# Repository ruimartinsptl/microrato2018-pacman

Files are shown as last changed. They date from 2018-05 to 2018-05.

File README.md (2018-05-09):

# PACMAN
## Micro Rato 2018
Neste repositório encontram o material necessário para criarem um robot micro-rato igual ao da nossa equipa. Disponibilizamos aqui:

* Modelos 3D
* Codigo para fazerem o vosso proprio farol emissor
* Esquema com as ligações de electronica
* Classes criadas por nós para aceder ao Hardware com alguns exemplos de utilização no código main
* Ferramenta de Debug em Python
* Relatório apresentado ao Juri

De forma a sermos mais eficientes, utilizamos o platformio para gerar os nossos makefiles, e utilizamos o CLion como IDE. Para comunicar com o robot usamos um ESP acoplado ao rato que tinha como função programar o rato remotamente via wifi. Entras aqui a respectiva documentação.

### O Robot:

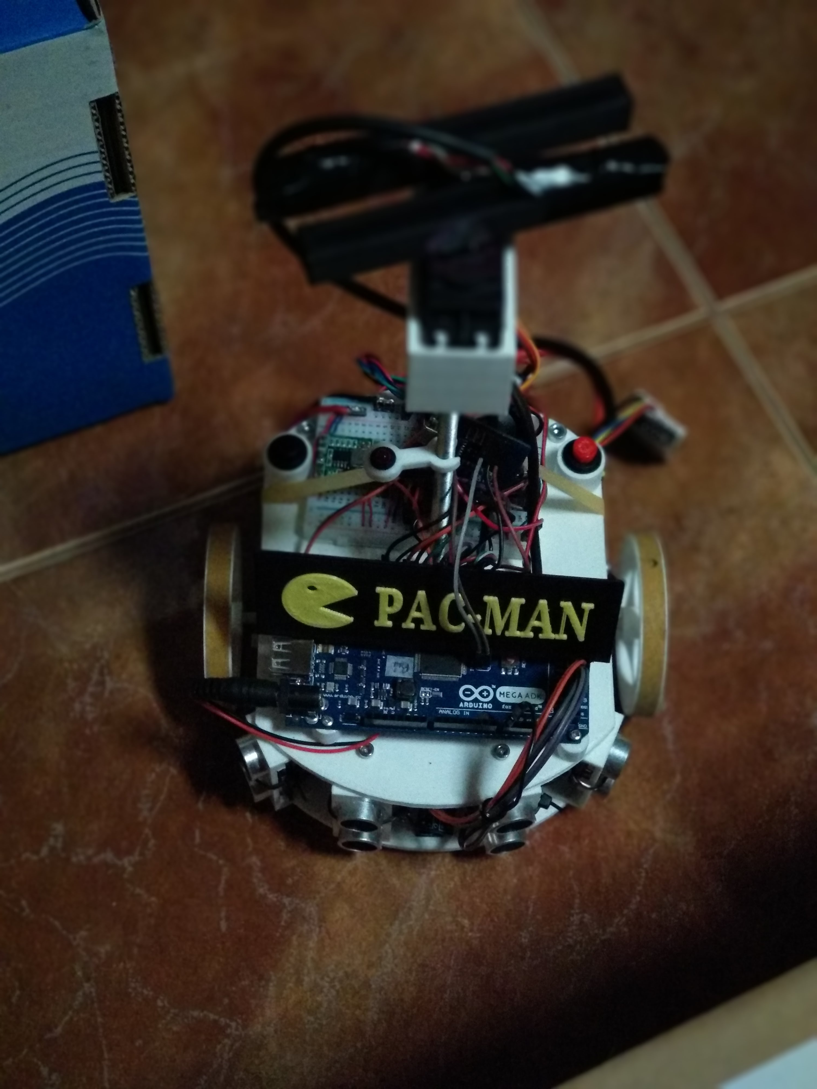
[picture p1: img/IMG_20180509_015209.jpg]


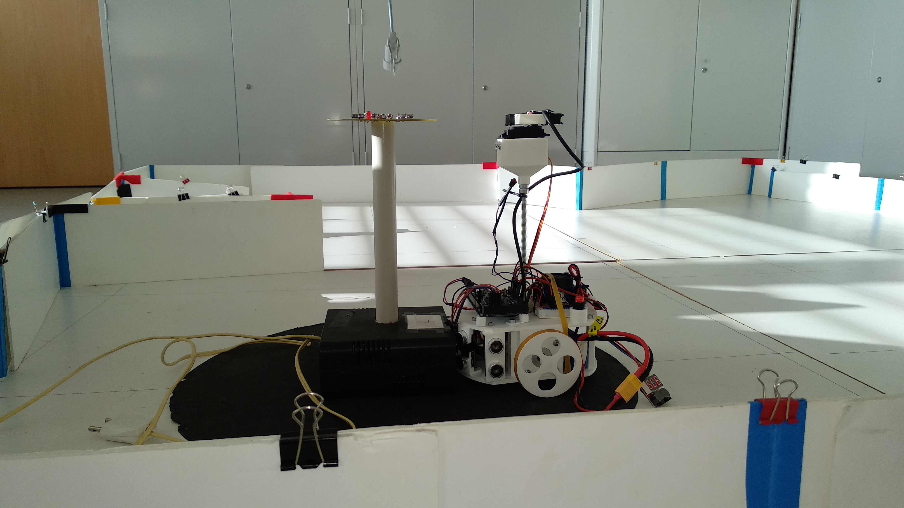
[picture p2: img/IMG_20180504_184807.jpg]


### Visualização gráfica dos valores dos sensores, e utilização do "farol portatil":

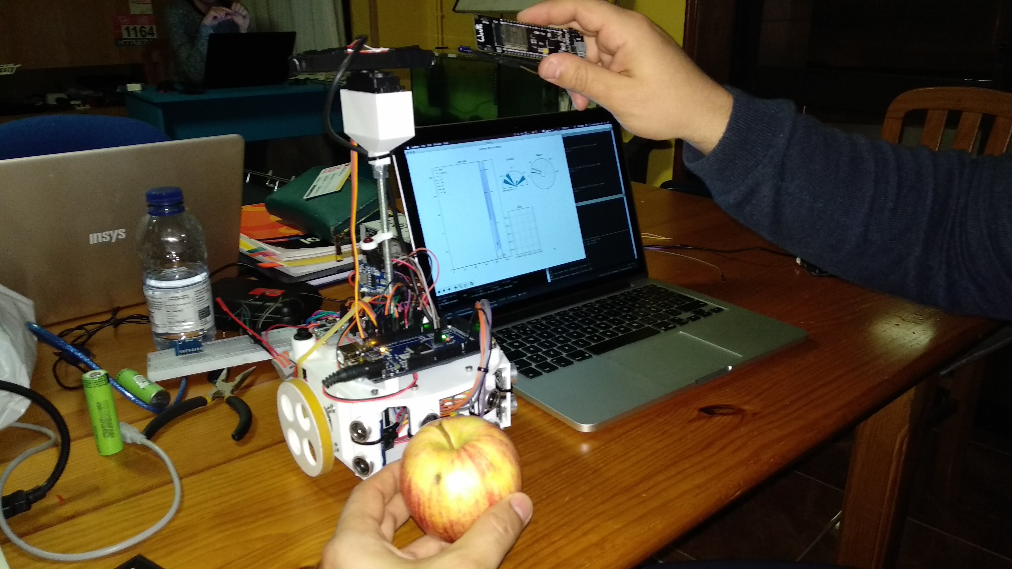
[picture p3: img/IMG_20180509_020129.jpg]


### Ligações:

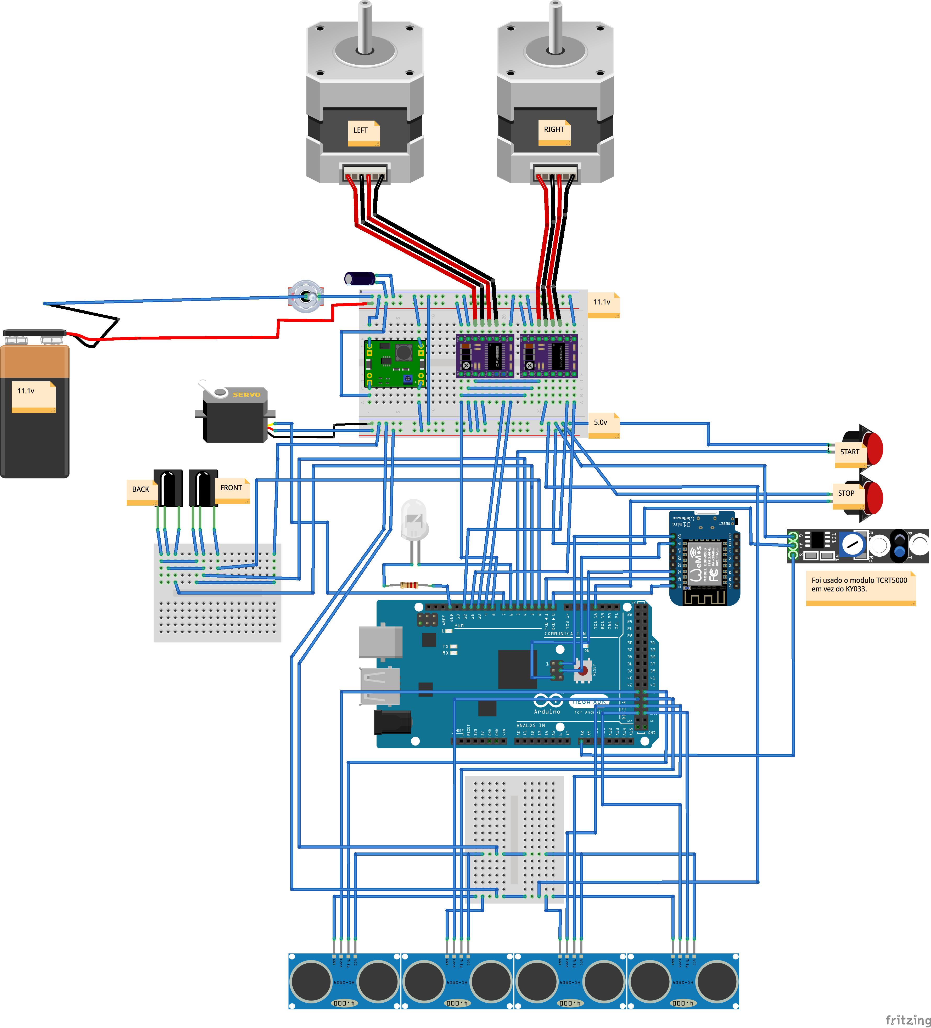
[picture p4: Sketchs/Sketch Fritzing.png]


### Modelos 3D

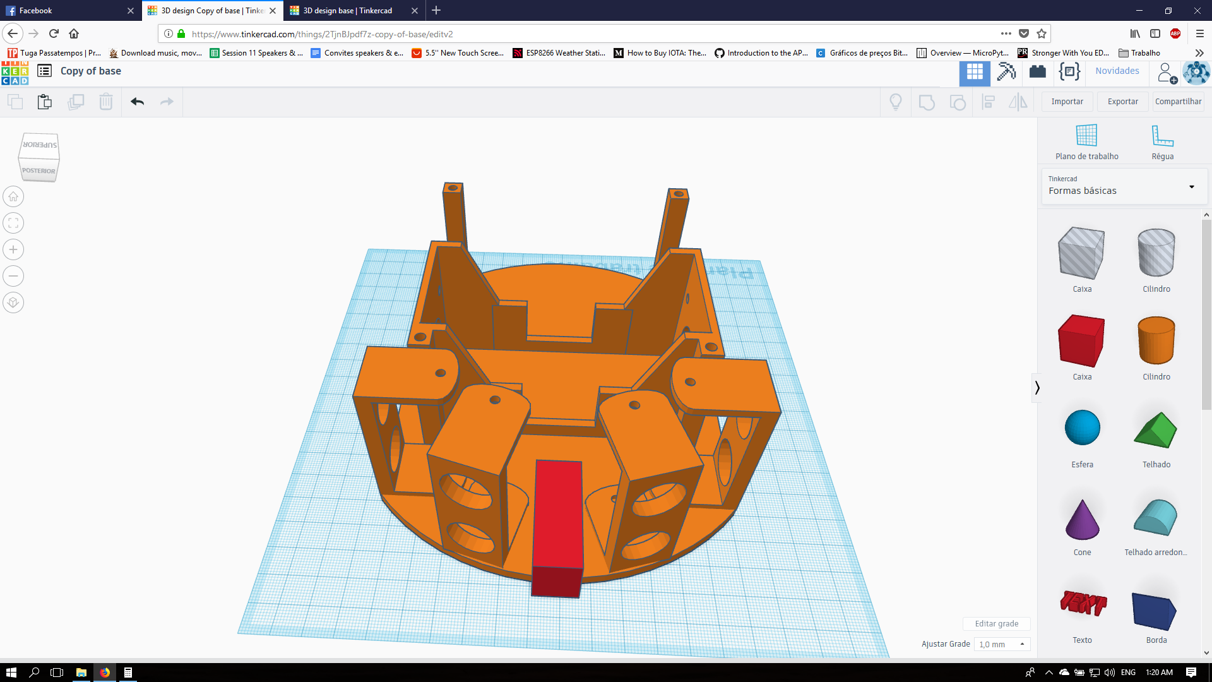
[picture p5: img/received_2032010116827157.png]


Tinkercad: [https://www.tinkercad.com/users/0B3h3IggmHm-fmmf](https://www.tinkercad.com/users/0B3h3IggmHm-fmmf)

Thingiverse: [https://www.thingiverse.com/thing:2939716](https://www.thingiverse.com/thing:2939716)

## Equipa

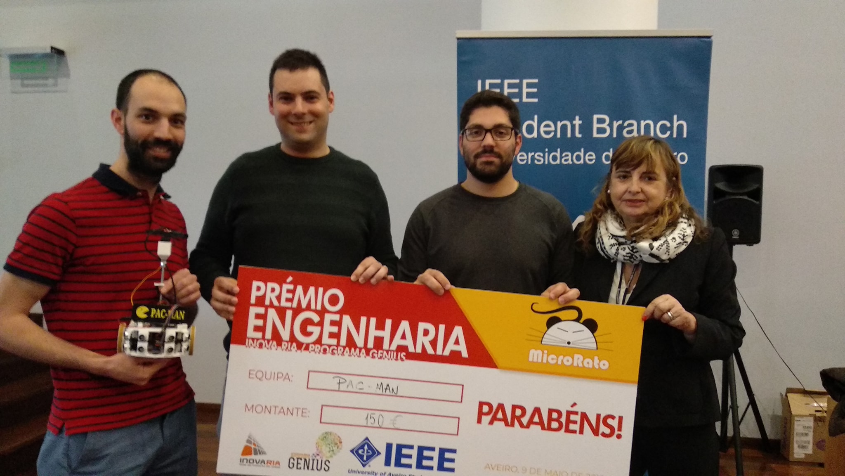
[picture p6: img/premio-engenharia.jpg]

Fábio Ferreira, Rui Martins, Pedro Costa

---
Parabéns a toda a organização e aos restantes concorrentes.

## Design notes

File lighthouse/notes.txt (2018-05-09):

https://techtutorialsx.com/2017/06/15/esp32-arduino-led-pwm-fading/

int freq = 5000;
int ledChannel = 0;
int resolution = 8;

void setup() {

  ledcSetup(ledChannel, freq, resolution);
  ledcAttachPin(LED_BUILTIN, ledChannel);

}

void loop() {

  for (int dutyCycle = 0; dutyCycle <= 255; dutyCycle++){
ledcWrite(ledChannel, dutyCycle);
delay(7);
}

for (int dutyCycle = 255; dutyCycle >= 0; dutyCycle--){
     ledcWrite(ledChannel, dutyCycle);
     delay(7);
  }

}

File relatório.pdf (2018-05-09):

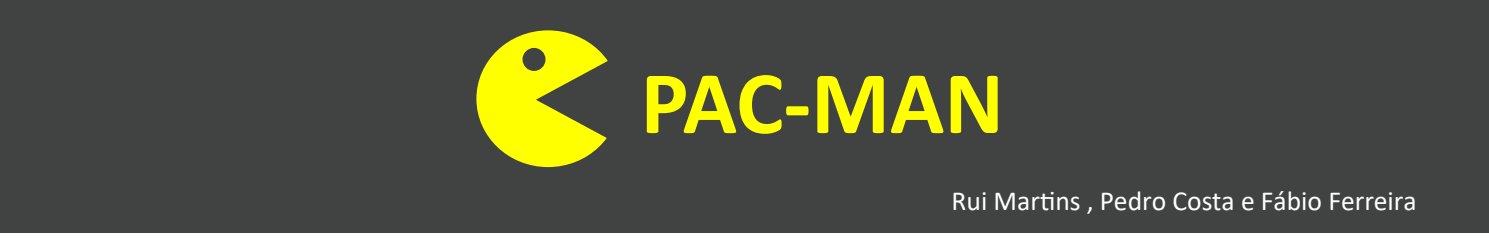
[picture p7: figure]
PAC-MAN

Rui Martins , Pedro Costa e Fábio Ferreira

- Utilizada arquitetura de agente reativo , utilizando bibliotecas open-source, com o objectivo de disponibilização do firmware à comunidade.
- Desenvolvmento de um beacon móvel com recurso a esp32 + led IR + bateria 18650, que permite rápidamente testar várias situações sem necessitar de estar fixo a uma localização.
- Desenvolvimento e debugging wifi através do uso de esp8266 com firmware esp-link para upload e serial output do firmware, facilmente removido aquando da prova de modo a cumprir os regulamentos.

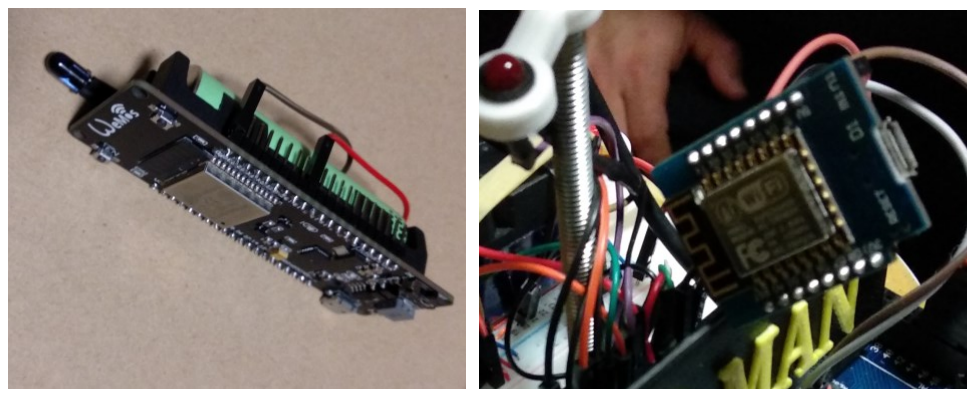
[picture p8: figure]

- Aplicação de monitorização em tempo real das variáveis de estado e debugging, com apoio visual gráfico de modo a rapido e facilmente detectar problemas e realizar calibração.
- Desenvolvimento da estrutura modular para fácil impressão 3D em ferramentas gratuitas e de utilização simples (Thinkercad)
- Desponibilização dos designs para a comunidade para desenvolvimento futuro.
- Materiais de relativo baixo custo e acessíveis de forma a tornar a sua construção facilitada a um público maior (como é o exemplo a utilização do berlinde de suporte e elásticos nas rodas) e utilização de motores stepper devido à sua disponibilidade em impressoras 3D.

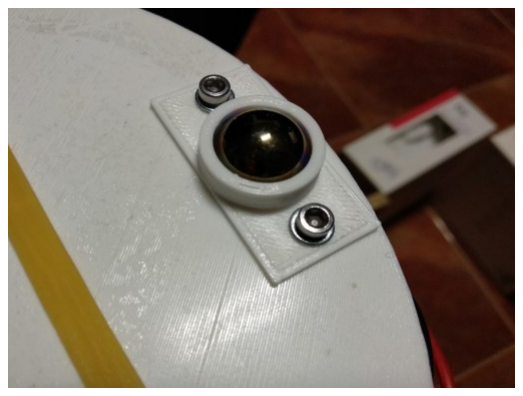
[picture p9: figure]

- Utilização de sensores de ultrasons, de baixo custo, colocados de maneira a aproveitar ao máximo o seu ângulo de atuação sem prejudicar o seu correcto funcionamento.
- Dois receptores de IR permitem utilizar motor servo de 180°, e mesmo com um motor servo que rode 360° fazer o scan 2 vezes mais rápido sem mover o corpo do micro-rato.

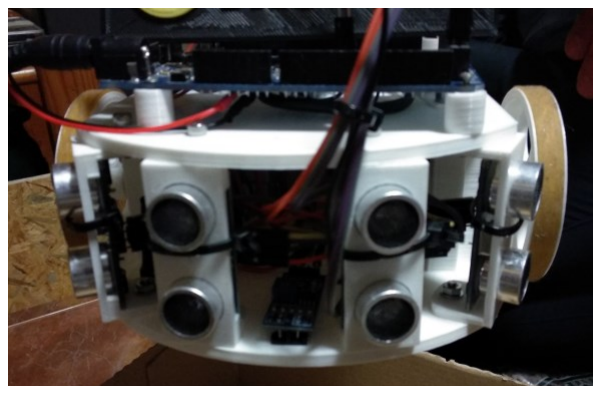
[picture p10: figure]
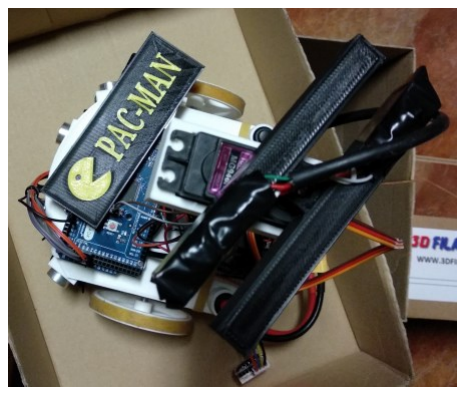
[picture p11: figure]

- O micro-rato é redondo com apenas duas rodas centrais de modo a poder rodar sobre si sem arriscar contacto com obstáculos bem como permitir uma aplicação mais simplificada de odometria no mesmo.
- Foi reduzido ao mínimo tamanho possível (cerca de metade do permitido) de modo a que possa mais facilmente evitar obstáculos e dando-lhe mais liberdade de movimentação
Design e Concepção | Software e Desenvolvimento

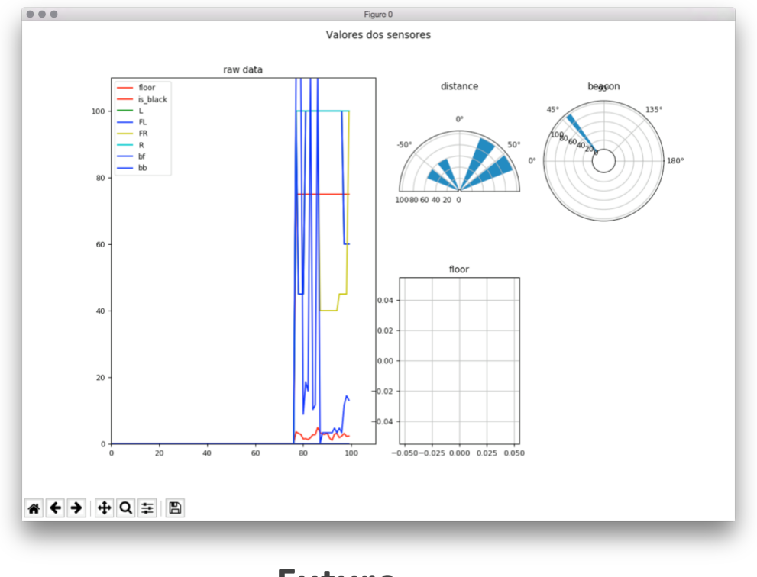
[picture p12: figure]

### Futuro

- Utilização de um berlinde adicional na frente.
- Inicialmente foi utilizado arduino due com funcionalidade de usb host com objectivo de utilização de um rato óptico usb para facilitar a odometria.
- Incluir giroscópio e acelerômetro (MPU-6050) para melhor a odometria em caso de steps perdidos.

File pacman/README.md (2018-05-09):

+ src - Codigo principal do micro rato
+ exp - Experiencias, tem pequenos pedacos de codigo que podem ser colados no main para testes

# Se usar conda:
```bash
conda create --name microrato python=2.7
conda activate microrato
```
```bash
pip install -U platformio

pio lib install "Servo"
pio lib install "AccelStepper"
pio lib install "IRremote"
```

Iniciar o projecto pela primeira vez para criar ficheiros do cmake:
```bash
pio init -b <nanoatmega328|megaADK|dueUSB> --ide clion
```

Upload para uma board especifica quando houver varios arduinos ligados por USB:
```bash
pio run -t upload -e <nano|due|mega> [ --upload-port /dev/cu.usbmodem1411 ]
pio run -t upload -e nano
pio run -t upload -e due  # [env:due] é um alias para [env:dueUSB]
pio run -t upload -e mega
```

CLEAN:
```bash
pio run -t clean
```
```bash
miniterm.py --exit-char 24 --raw /dev/cu.usbmodem1411 115200 # [Exit char é para CTRL X]
```

Abreviado:
```bash
pio run -t upload -e due && miniterm.py --exit-char 24 --raw /dev/cu.usbmodem1411 115200
pio run -t upload -e mega && miniterm.py --exit-char 24 --raw /dev/cu.usbmodem1411 115200
```

https://matplotlib.org/1.5.3/faq/virtualenv_faq.html

# Upload via ESP:
pio run && ./megaflash.sh 192.168.1.177 .pioenvs/mega/firmware.hex

# Ler serial da rede com netcat:
nc 192.168.1.177 23

# Usar a aplicação de gráficos em tempo real
##Via USB Serial: 
```bash
python serial_read_v2.py -p <serial_port>
```

##Via ESP log:
1. Criar uma interface serial virtual com para pordutor e consumidor: 
```bash
socat -d -d PTY,link=./ttydevice,raw,echo=0 PTY,link=./ttyclient,raw,echo=0
```
> NOTA: Se necessário instalar socat com (em macOS):
> ```bash brew install socat```

2. Cricar o produtor fazendo redirect da ligação Telnet para Serial
```bash
python tcp_serial_redirect.py -c 192.168.1.177:23 ttyclient 115200
```

3. Iniciar a aplicação 
```bash
python serial_read_v2.py -p ttydevice
```

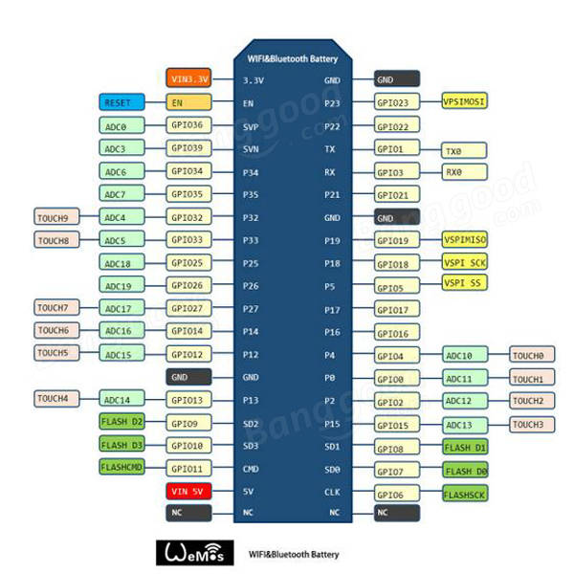
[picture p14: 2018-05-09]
lighthouse/docs/wemos_pinout.jpg

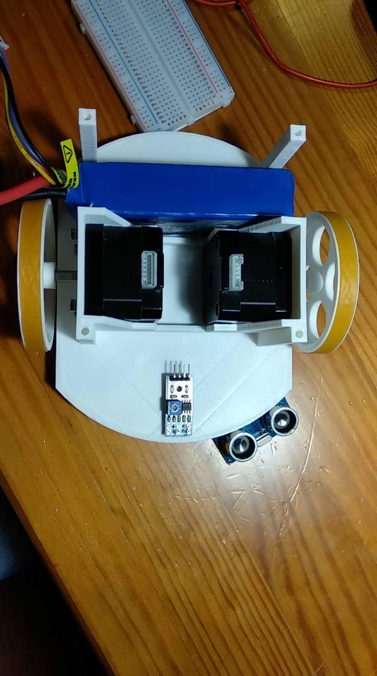
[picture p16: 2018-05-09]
img/1st-version-before-change-motors.jpeg

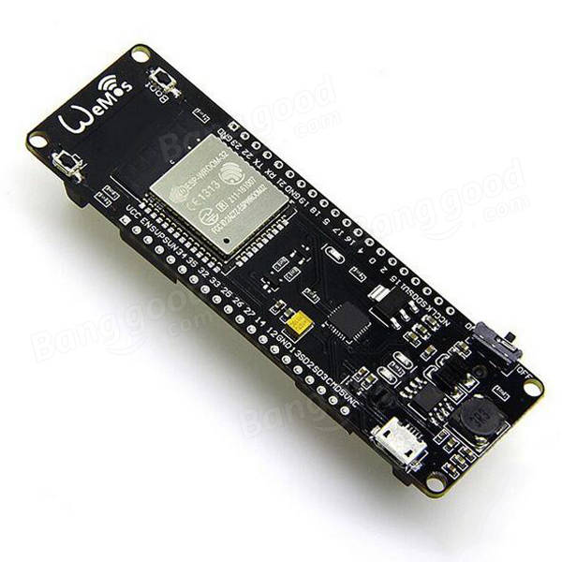
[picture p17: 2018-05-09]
lighthouse/docs/wemos.jpg

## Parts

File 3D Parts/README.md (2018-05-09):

Download 3D parts here: 
https://www.thingiverse.com/thing:2939716

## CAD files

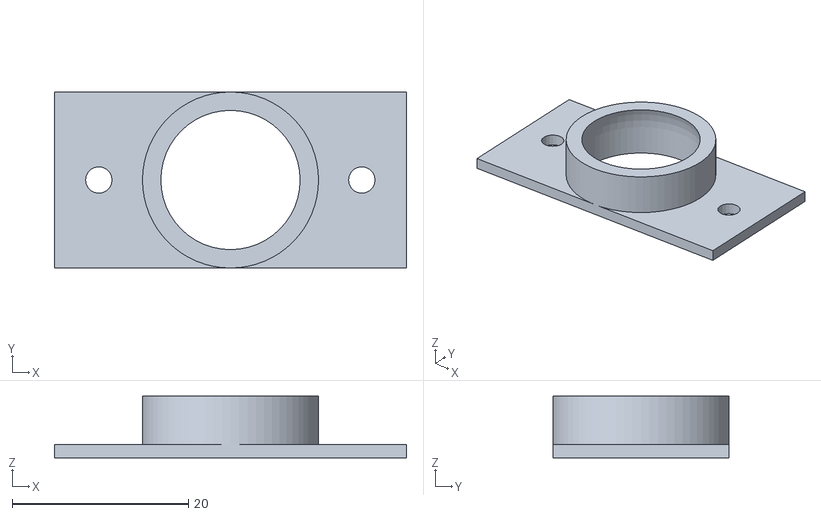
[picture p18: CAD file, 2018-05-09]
3D Parts/Berlinde.stl
40.0 x 20.0 x 7.00

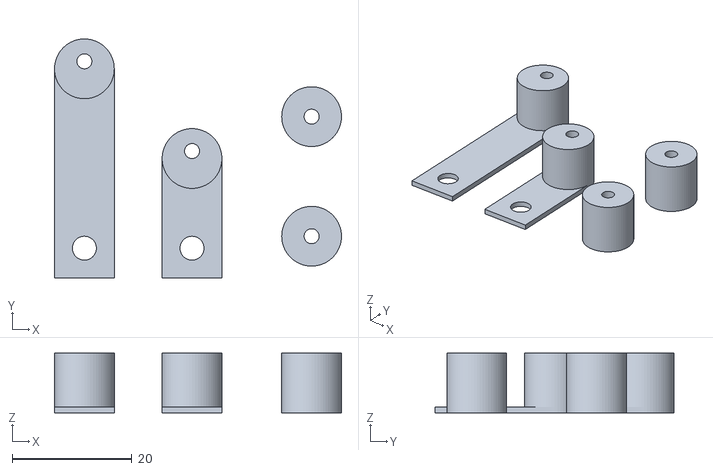
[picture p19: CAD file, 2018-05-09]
3D Parts/bases_arduino.stl
48.0 x 40.0 x 10.0

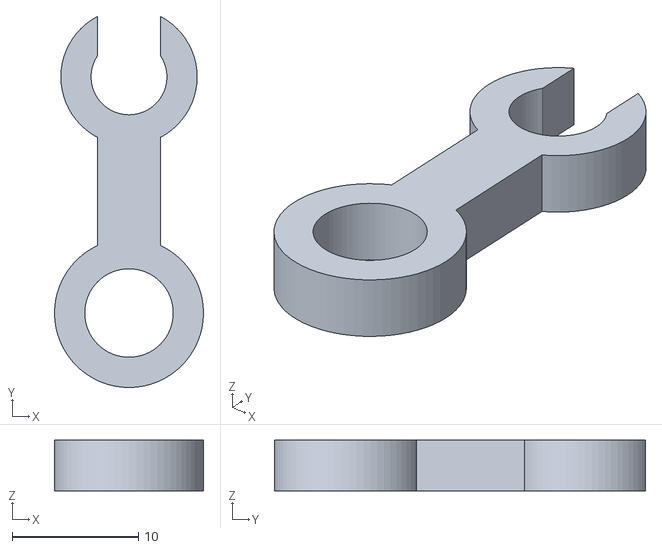
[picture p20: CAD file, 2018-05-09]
3D Parts/suporte_led.stl
11.8 x 29.4 x 4.00

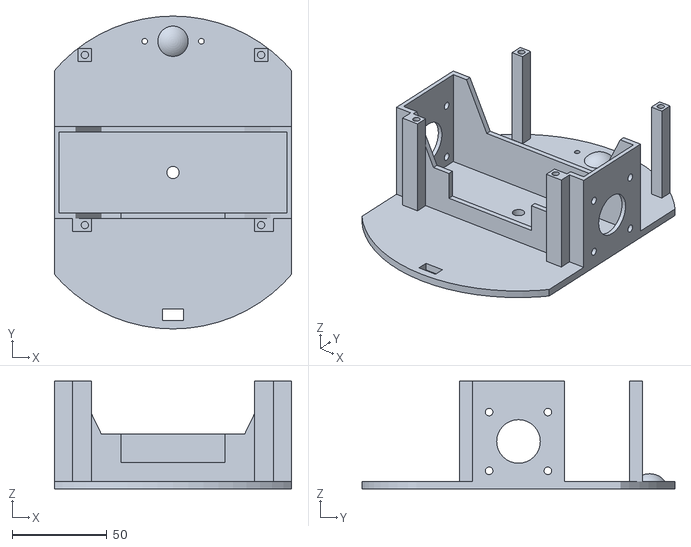
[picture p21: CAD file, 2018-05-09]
3D Parts/base.stl
125.0 x 165.0 x 56.8

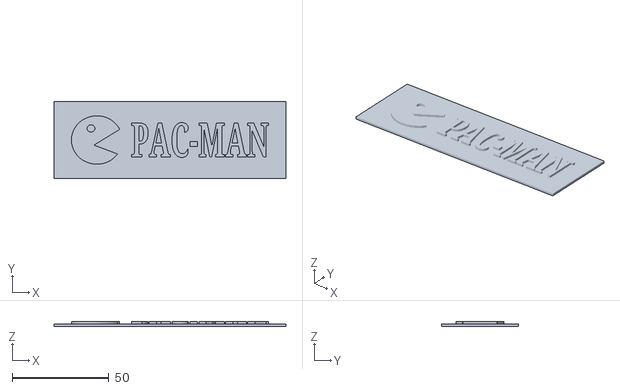
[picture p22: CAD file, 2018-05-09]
3D Parts/Nome.stl
120.0 x 40.0 x 2.40

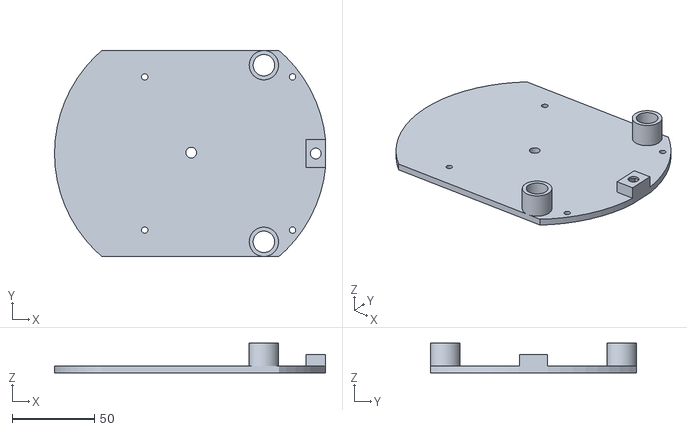
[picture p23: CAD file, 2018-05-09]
3D Parts/plataforma.stl
164.5 x 125.0 x 18.0

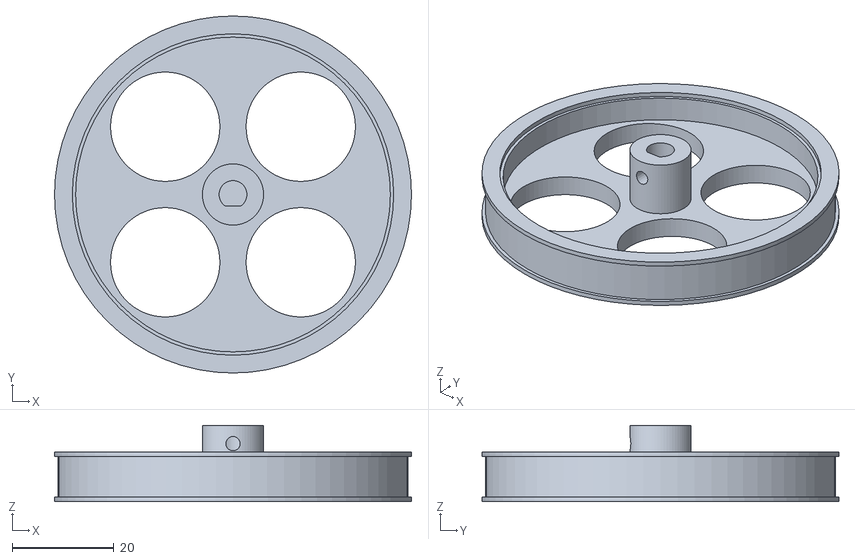
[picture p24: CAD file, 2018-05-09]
3D Parts/roda.stl
70.0 x 70.0 x 15.0

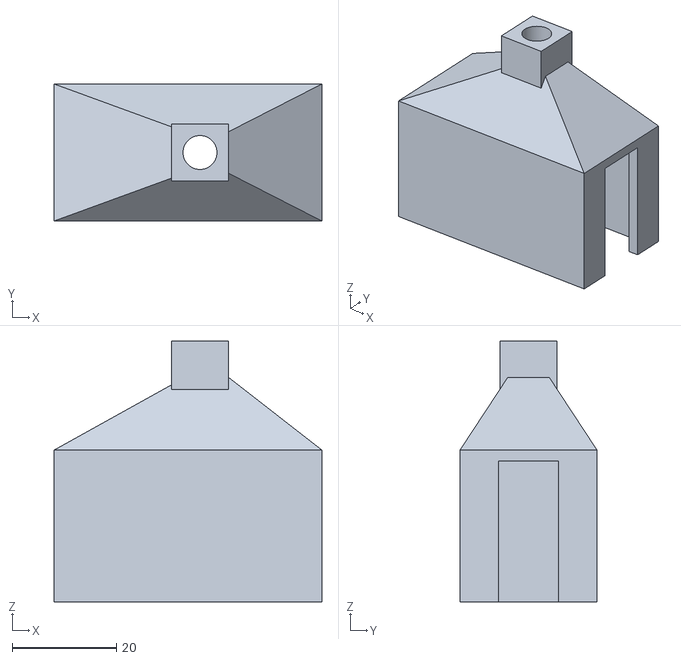
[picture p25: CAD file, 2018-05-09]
3D Parts/farol_motor.stl
51.4 x 26.3 x 50.0

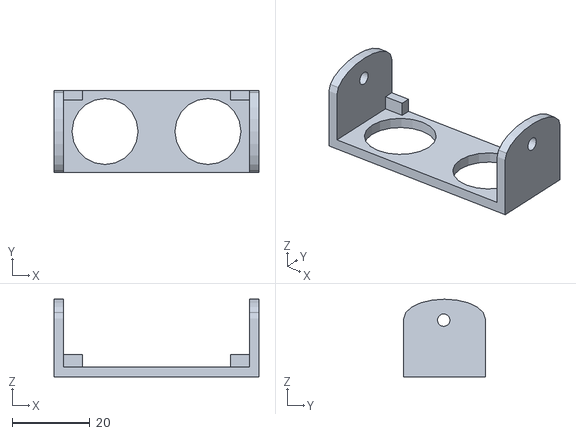
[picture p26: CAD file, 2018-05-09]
3D Parts/suporte_sensor_ultrasons.stl
52.8 x 21.0 x 20.0

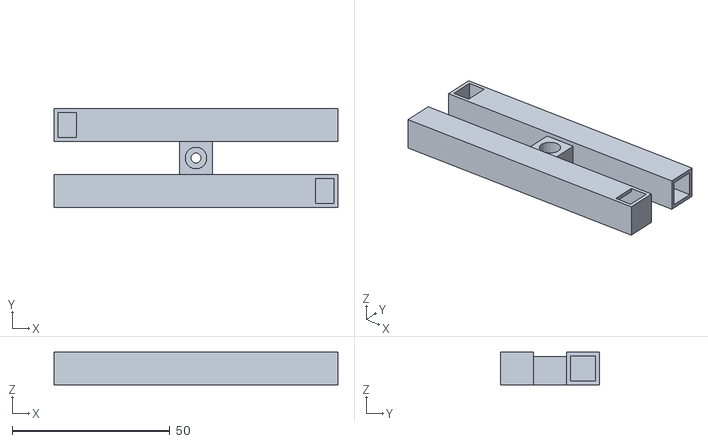
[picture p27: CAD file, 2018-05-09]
3D Parts/farol_receptor_led.stl
90.0 x 31.3 x 10.4

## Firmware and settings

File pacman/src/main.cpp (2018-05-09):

// Este documento está pré-preenchido mas não contem o algoritmo usado no concurso.
// Serve de exemplo.

#include <Arduino.h>
#include <Servo.h>
#include <AccelStepper.h>
#include <NewPing.h>
#include "pins.h"
#include "constants.h"
#include "state_machine.h"
#include "motors_steper.h"
#include "led_red.h"
#include "FloorSensor.h"
#include "BeaconSensor.h"

#if defined(ARDUINO_AVR_NANO) || defined(ARDUINO_AVR_ADK) || defined(ARDUINO_AVR_MEGA2560)

#else
// XPTO
// DUE
// Comentar o seguinte define quando usar a porta de programming, descomentar quando se usar a porta USB nativa
#define Serial SerialUSB
// #define Serial Serial1
#endif
#define ENABLE_DEBUG


// (...YOUR CODE HERE...)

AccelStepper stepper_left(AccelStepper::DRIVER, PIN_MOTOR_LEFT_STEP, PIN_MOTOR_LEFT_DIR);
AccelStepper stepper_right(AccelStepper::DRIVER, PIN_MOTOR_RIGHT_STEP, PIN_MOTOR_RIGHT_DIR);

// NewPing setup of pins and maximum distance.
NewPing sonar_left(PIN_TRIG_LEFT, PIN_ECHO_LEFT, PING_MAX_DISTANCE / 10);
NewPing sonar_front_left(PIN_TRIG_FRONTL, PIN_ECHO_FRONTL, PING_MAX_DISTANCE / 10);
NewPing sonar_front_right(PIN_TRIG_FRONTR, PIN_ECHO_FRONTR, PING_MAX_DISTANCE / 10);
NewPing sonar_right(PIN_TRIG_RIGHT, PIN_ECHO_RIGHT, PING_MAX_DISTANCE / 10);

FloorSensor floor_sensor(PIN_FLOOR_SENSOR, THRESHOLD_FLOOR_SENSOR);

BeaconSensor beacon(PIN_BEACON_FRONT, PIN_BEACON_BACK,
                    PIN_BEACONS_ENABLE, PIN_MOTOR_SERVO,
                    BEACON_MIN_FREQ_THRESHOLD,
                    BEACON_MAX_FREQ_THRESHOLD,
                    BEACON_MIN_PWM_THRESHOLD,
                    BEACON_MAX_PWM_THRESHOLD,
                    MOTOR_SERVO_0,
                    MOTOR_SERVO_180);

// (...YOUR CODE HERE...)

uint32_t distance_left = 0, distance_right = 0, distance_frontL = 0, distance_frontR = 0;
int beacon_angle = 0;
bool led_is_on = false;
bool beacon_front_is_on = false;
bool beacon_back_is_on = false;
uint8_t id_sensor_to_read = 0;

// (...YOUR CODE HERE...)

void kill_motors() {
    stepper_left.stop();
    stepper_right.stop();
}

void refresh_all_distance_sensors() {
    distance_left = (sonar_left.ping_cm() * 10);
    distance_right = (sonar_right.ping_cm() * 10);
    distance_frontR = (sonar_front_right.ping_cm() * 10);
    distance_frontL = (sonar_front_left.ping_cm() * 10);
}


void refresh_one_distance_sensors(uint8_t id) {
//    Serial.print("SENSOR: "); Serial.println(id);
    switch (id) {
        case 1:
            distance_left = sonar_left.ping_cm() * 10;
            break;
        case 2:
            distance_frontL = sonar_front_left.ping_cm() * 10;
            break;
        case 3:
            distance_frontR = sonar_front_right.ping_cm() * 10;
            break;
        case 4:
            distance_right = sonar_right.ping_cm() * 10;
            break;
    }
}


void do_things_on_cheese() {
    // (...YOUR CODE HERE...)
}

void sinalize_end_with_led() {
    // (...YOUR CODE HERE...)
}

// TEST ////////////////////////////////////////////////////////////////////////////////////////////////////////////////

void test_all() {
    Serial.println("Running test_all()...");

    // LED
    Serial.println("LED...");
    for (int i = 0; i < 10; i++) {
        if (i % 2 == 0)
            turn_on_led_red();
        else
            turn_off_led_red();
        delay(150);
    }
    Serial.println("LED... OK\n");

    // Main motors
    Serial.println("Motors...");
    turn_on_main_motors();
    stepper_left.setCurrentPosition(0);
    stepper_right.setCurrentPosition(0);
    aux1 = stepper_left.currentPosition() + PERIMETER_ROBOT_PERIMETER / 2 * STEPS_MM;
    aux2 = stepper_right.currentPosition() - PERIMETER_ROBOT_PERIMETER / 2 * STEPS_MM;
    stepper_left.moveTo(aux1);
    stepper_right.moveTo(aux2);
    while (mouse_state != STATE_MOUSE_ABORTED and
           (stepper_left.currentPosition() < (aux1) or stepper_right.currentPosition() > (aux2))) {
        stepper_left.run();
        stepper_right.run();
    }

    // Main motors
    for (uint_fast32_t i = 100000; i > 0; i--) {
        stepper_left.run();
        stepper_right.run();
    }
    turn_off_main_motors();
    Serial.println("Motors... OK\n");

    // Servo
    Serial.println("Servo...");
    beacon.motor_servo_write(0);
    beacon.motor_servo_write(180);
    beacon.motor_servo_write(90);
    Serial.println("Servo... OK\n");

    // Sensores da frente
    Serial.println("Sensores distancia...");
    refresh_all_distance_sensors();
    Serial.print(" L: ");
    Serial.print(distance_left);
    Serial.println("mm");
    Serial.print("FL: ");
    Serial.print(distance_frontL);
    Serial.println("mm");
    Serial.print("FR: ");
    Serial.print(distance_frontR);
    Serial.println("mm");
    Serial.print(" R: ");
    Serial.print(distance_right);
    Serial.println("mm");
    Serial.println("Sensores distancia... OK\n");

    // Sensor do chão
    Serial.println("Sensor chão...");
    Serial.print("Chão: ");
    Serial.print(floor_sensor.get_value());
    Serial.print("\t is black:");
    Serial.println(floor_sensor.is_black_on_floor());
    Serial.println("Sensor chão... OK\n");

    Serial.println("Running test_all()... OK");
}

void test_inputs_all() {
    // Sensor do chão
    if (floor_sensor.is_black_on_floor()) {
        turn_on_led_red();
    } else {
        turn_off_led_red();
    }

    Serial.println("Sensor chão...");
    Serial.print("Chão: ");
    Serial.print(floor_sensor.get_value());
    Serial.print("\t is black:");
    Serial.println(floor_sensor.is_black_on_floor());
    Serial.println("Sensor chão... OK\n");

    // Sensores da frente
    Serial.println("Sensores distancia...");
    refresh_all_distance_sensors();
    Serial.print(" L: ");
    Serial.print(distance_left);
    Serial.println("mm");
    Serial.print("FL: ");
    Serial.print(distance_frontL);
    Serial.println("mm");
    Serial.print("FR: ");
    Serial.print(distance_frontR);
    Serial.println("mm");
    Serial.print(" R: ");
    Serial.print(distance_right);
    Serial.println("mm");
    Serial.println("Sensores distancia... OK\n");

    // Beacons
    Serial.println("Beacons...");
//    Serial.print("BEACON FRONT: "); Serial.println(analogRead(beacon_front));
//    Serial.print("BEACON BACK: "); Serial.println(analogRead(beacon_front));
    Serial.println("BEACON FRONT:");

    Serial.println("Running test_all()... OK");
}

// TEST ////////////////////////////////////////////////////////////////////////////////////////////////////////////////
// /////////////////////////////////////////////////////////////////////////////////////////////////////////////////////

// INTERRUPTIONS ///////////////////////////////////////////////////////////////////////////////////////////////////////
void int_stop_pressed() {  // ISR stop button
    // (...YOUR CODE HERE...)
}

// INTERRUPTIONS ///////////////////////////////////////////////////////////////////////////////////////////////////////
// /////////////////////////////////////////////////////////////////////////////////////////////////////////////////////

void set_pins_mode() {
    // PINS
    pinMode(PIN_STOP, INPUT_PULLUP);
    pinMode(PIN_START, INPUT_PULLUP);
    pinMode(PIN_LED_RED, OUTPUT);

    pinMode(PIN_MOTORS_EN, OUTPUT);
    pinMode(PIN_MOTOR_LEFT_DIR, OUTPUT);
    pinMode(PIN_MOTOR_LEFT_STEP, OUTPUT);
    pinMode(PIN_MOTOR_RIGHT_DIR, OUTPUT);
    pinMode(PIN_MOTOR_RIGHT_STEP, OUTPUT);

    pinMode(PIN_TRIG_LEFT, OUTPUT);
    pinMode(PIN_ECHO_LEFT, INPUT);  //US SENSORS HC-SR04
    pinMode(PIN_TRIG_RIGHT, OUTPUT);
    pinMode(PIN_ECHO_RIGHT, INPUT);  //US SENSORS HC-SR04
    pinMode(PIN_TRIG_FRONTL, OUTPUT);
    pinMode(PIN_ECHO_FRONTL, INPUT);  //US SENSORS HC-SR04
    pinMode(PIN_TRIG_FRONTR, OUTPUT);
    pinMode(PIN_ECHO_FRONTR, INPUT);  //US SENSORS HC-SR04
////    pinMode(PIN_COLOR_FLOOR, INPUT);  // IR floor
}

void print_info() {
    Serial.print("BAUDRATE:\t");
    Serial.println(BAUDRATE);
    Serial.print("TICK_MAIN_PROCESS:\t\t");
    Serial.println(TICK_MAIN_PROCESS);
    Serial.print("TIMEOUT:\t");
    Serial.print(TIMEOUT / 1000);
    Serial.println(" s");
    Serial.print("STEPS_MM:\t");
    Serial.println(STEPS_MM);
    Serial.print("WHEEL_PERIMETER:\t");
    Serial.print(WHEEL_PERIMETER);
    Serial.println(" mm");
    Serial.print("WHEEL_RADIUS:\t");
    Serial.print(WHEEL_RADIUS);
    Serial.println(" mm");
}

void send_variables_to_serial(bool force = false) {
    currentMillis = millis();
    if (force || (currentMillis - previousMillis_t_print_to_serial) >= TICK_PRINT_TO_SERIAL) {
        previousMillis_t_print_to_serial = currentMillis;
        Serial.print("--> "); // START
        Serial.print(floor_sensor.get_value());
        Serial.print(" "); // Valor do sensor do chão
        Serial.print(floor_sensor.is_black_on_floor());
        Serial.print(" "); // É preto ou não
        Serial.print(distance_left);
        Serial.print(" "); // Valor sensor esquerdo
        Serial.print(distance_frontL);
        Serial.print(" "); // Valor sensor esquerdo frente
        Serial.print(distance_frontR);
        Serial.print(" "); // Valor sensor direito frente
        Serial.print(distance_right);
        Serial.print(" "); // Valor sensor direito
        Serial.print(beacon_angle);
        Serial.print(" "); // Angulo do farol
        Serial.print(current_position.x);
        Serial.print(";");
        Serial.print(current_position.y);
        Serial.print(";");
        Serial.print(current_position.theta); // em radianos
        Serial.print(" "); // Position
        Serial.print(led_is_on);
        Serial.print(" "); // Led está ligado?
        Serial.print(mouse_state);
        Serial.print(" "); // Estado do robot
        Serial.print(stepper_left.currentPosition());
        Serial.print(";");
        Serial.print(stepper_right.currentPosition());
        Serial.print(" ");
        Serial.print('\n'); // END
    }
}

void setup() {
#ifdef ENABLE_DEBUG
    Serial.println("Setup...");
#endif
    Serial.begin(BAUDRATE);
//    while(!Serial) {yield();} // Pode bloquear // XPTO // Descomentar quando tiver ligado por cabo
    set_pins_mode();

//    turn_off_beacon();
    turn_off_main_motors();
    turn_off_led_red();
//    turn_on_servo();
//    set_servo_degree(90);
//    turn_off_servo();

    stepper_left.setMaxSpeed(MOTORS_MAX_SPEED);
    stepper_left.setAcceleration(MOTORS_ACELERATION);
    stepper_right.setMaxSpeed(MOTORS_MAX_SPEED);
    stepper_right.setAcceleration(MOTORS_ACELERATION);
    stepper_right.setPinsInverted(true, false, false);

    beacon.begin();

    beacon.motor_servo_write(0);
    beacon.motor_servo_write(180);
    beacon.motor_servo_write(90);

    print_info();

//    test_all();

    attachInterrupt(digitalPinToInterrupt(PIN_STOP), int_stop_pressed,
                    FALLING); // RISING - to trigger when the pin goes from low to high; FALLING - for when the pin goes from high to low;
#ifdef ENABLE_DEBUG
    Serial.println("Setup... OK");
#endif
}

void loop() {
//    test_inputs_all();
//    test_all();
//    turn_on_led_red();
    mouse_state = STATE_MOUSE_WAITTING_TO_START;
    turn_off_led_red();
    turn_off_main_motors();
#ifdef ENABLE_DEBUG
    Serial.print("Waiting for START...");
#endif
    // WAITTING START BUTTON
    while (digitalRead(PIN_START) == HIGH) {
        currentMillis = millis();
        if ((currentMillis - previousMillis_t_read_sensors) >= TICK_READ_SENSORS) {
            previousMillis_t_read_sensors = currentMillis;
            refresh_all_distance_sensors();
        }

        send_variables_to_serial();
        yield();
    }

    // PIN_START pressed
    time_start = millis();
#ifdef ENABLE_DEBUG
    Serial.print("PIN_START pressed\n");
#endif
    turn_on_main_motors();
    stepper_left.stop();
    stepper_right.stop();
    stepper_left.setCurrentPosition(0);
    stepper_right.setCurrentPosition(0);

    beacon.motor_servo_write(90);
    mouse_state = STATE_MOUSE_SEARCH_BEACON;
    journey_state = STATE_JOURNEY_GOING_TO_CHEESE;

    // Main while inside loop()
    while (mouse_state != STATE_MOUSE_ALL_DONE && mouse_state != STATE_MOUSE_ABORTED) {

        // (...YOUR CODE HERE...)

        send_variables_to_serial();
        stepper_left.run();
        stepper_right.run();
    }

#ifdef ENABLE_DEBUG
    if (mouse_state == STATE_MOUSE_ALL_DONE) {
        Serial.print(
                "MAIN termina com sucesso, o rato fez tudo o que tinha a fazer. Rato vai ficar à espera de novo START");
    }

    if (mouse_state == STATE_MOUSE_ABORTED) {
        Serial.print("MAIN termina porque foi premido ABORT. Rato vai ficar de novo no estado à espera de START");
    }
#endif
}

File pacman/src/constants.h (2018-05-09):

#ifndef PACMAN_CONSTANTS_H
#define PACMAN_CONSTANTS_H



#define TIMEOUT ((3*60*1000) - 4000) // 3 Minutos até timeout - 4 segundos



#define BAUDRATE 115200 // 115200 ; 2000000; 230400 ; 500000
#define TICK_MAIN_PROCESS 50 //t(ms)
#define TICK_READ_SENSORS 50 // t(ms) Na documentação diz para não fazer mais de 20 pings por segundo
#define TICK_PRINT_TO_SERIAL 500 // t(ms) Na documentação diz para não fazer mais de 20 pings por segundo
#define TICK_FIND_SENSOR 20 * 1000 // t(ms) Na documentação diz para não fazer mais de 20 pings por segundo

#define DISTANCE_BETWEEN_WHEELS 150 // <<<<<<<<<<<<<<<<<<<<<<<<<<<<<<<<<<<<<<<<<<<<<<<<<<<<<<<<<<<<<<<<<<<<<<<<<<<<<<<<<
#define PERIMETER_ROBOT_PERIMETER (2*PI*DISTANCE_BETWEEN_WHEELS/2) // Perimeter between wheels
#define WHEEL_RADIUS (70/2) // <<<<<<<<<<<<<<<<<<<<<<<<<<<<<<<<<<<<<<<<<<<<<<<<<<<<<<<<<<<<<<<<<<<<<<<<<<<<<<<<<<<<<<<<<
#define WHEEL_PERIMETER (2*PI*WHEEL_RADIUS) // 220mm // 2*PI*r // r=7/2=3.5
#define MOTOR_TOTAL_STEPS 200 // Total de steps do motor para dar uma volta
#define MOTOR_MICROSTEPS 8 // Quantos steps tem que dar para correr um step real

#define MOTORS_MAX_SPEED (160.0 * MOTOR_MICROSTEPS) // Ano passado 150
//#define MOTORS_MAX_SPEED (500.0 * MOTOR_MICROSTEPS) // Ano passado 150
#define MOTORS_ACELERATION (3000.0 * MOTOR_MICROSTEPS) // Ano passado 3000
// #define MOTORS_ACELERATION (1000.0 * MOTOR_MICROSTEPS) // Ano passado 3000

//const double PI = 3.141592;
//#define PI 3.141592
//const unsigned long TICK_MAIN_PROCESS = 50; //t(ms)

//#define STEPS_MM (WHEEL_PERIMETER / (MOTOR_TOTAL_STEPS * MOTOR_MICROSTEPS)) // Numero de steps por mm
#define STEPS_MM ((MOTOR_TOTAL_STEPS * MOTOR_MICROSTEPS) / WHEEL_PERIMETER) // Numero de steps por mm

#define PING_MAX_DISTANCE 300 // Em mm (será convertido para cm no main)

//#define THRESHOLD_FLOOR_SENSOR 300
#define THRESHOLD_FLOOR_SENSOR 150

#define NONE 0
#define LEFT 1
#define RIGHT 2

// SERVO CALIBRATION VALUES ////////////////////////////////////////////////////////////////////////////////////////////
// Values in degrees
//#define MOTOR_SERVO_0   18 // 15
//#define MOTOR_SERVO_180 177 // 175

// Values in time units
#define MOTOR_SERVO_0 729
#define MOTOR_SERVO_180 (2369 + 1)

// BEACON THRESHOLDS ///////////////////////////////////////////////////////////////////////////////////////////////////
#define BEACON_MIN_FREQ_THRESHOLD  550
#define BEACON_MAX_FREQ_THRESHOLD  650
#define BEACON_MIN_PWM_THRESHOLD   0.25
#define BEACON_MAX_PWM_THRESHOLD   0.35

#endif //PACMAN_CONSTANTS_H

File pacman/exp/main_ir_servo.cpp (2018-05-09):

//#define IR_PIN_INT
//#define IR_PIN_IRREMOTE
//#define IR_PIN_PWM

#include "pins.h"
#include <Arduino.h>
#include <Servo.h>

#ifdef IR_PIN_IRREMOTE
//#include <IRremote.h>
#endif
#ifdef IR_PIN_PWM
//#include "PWM.hpp"
#include "BeaconSensor.h"

#endif

//#if defined(ARDUINO_AVR_NANO) || defined(ARDUINO_AVR_ADK)
//#define IR_PIN 2
//#else
//#define Serial SerialUSB
//#define IR_PIN 22
//#endif

#define IR_PIN PIN_BEACON_FRONT

#ifdef IR_PIN_INT
void rising();
void falling();

boolean beacons_enabled = false;
volatile float pwm = 0;
volatile float period = 0;
volatile float p_period = 0;
volatile float freq = 0;
volatile uint32_t pwm_value_on = 0;
volatile uint32_t pwm_value_off = 0;
volatile uint32_t prev_time_on = 0;
volatile uint32_t prev_time_off = 0;

#endif

#ifdef IR_PIN_IRREMOTE
IRrecv irrecv(IR_PIN);
decode_results results;
#endif

Servo motor_servo_beacon;

#ifdef IR_PIN_PWM
//PWM pwm_front;
//PWM pwm_back;
//IR_PWM pwm_front;
//IR_PWM pwm_back;
#endif

// the setup function runs once when you press reset or power the board
void setup() {
    Serial.begin(115200);

//    while(!Serial);

#ifdef IR_PIN_IRREMOTE
    Serial.println("Enabling IRin");
    irrecv.enableIRIn(); // Start the receiver
    Serial.println("Enabled IRin");
#endif

    // initialize digital pin PIN_LED_RED as an output.
    pinMode(PIN_LED_RED, OUTPUT);
    pinMode(PIN_BEACONS_ENABLE, OUTPUT);
    pinMode(PIN_MOTOR_SERVO, OUTPUT);

#ifdef IR_PIN_INT
    pinMode(IR_PIN, INPUT);
    // when pin D22 goes high, call the rising function
    attachInterrupt(digitalPinToInterrupt(IR_PIN), rising, RISING);
//    attachInterrupt(0, falling, FALLING);
#endif

    // Servo
//    Serial.println("Servo...");
//    motor_servo_beacon.attach(PIN_MOTOR_SERVO);
//
//    Serial.println("0"); motor_servo_beacon.write(15);
//    delay(2000); Serial.println("0 OK");
//
//    Serial.println("180"); motor_servo_beacon.write(180);
//    delay(2000); Serial.println("180 OK");
//
//    Serial.println("90"); motor_servo_beacon.write(90);
//    delay(2000); Serial.println("90 OK");
//
//    Serial.println("Servo... OK\n");

//    int zero = 15;
//    for (int i = zero; i <= 180; i+=5) {
//        Serial.println(i); motor_servo_beacon.write(i);
//        delay(500); Serial.print(i); Serial.println(" OK");
//    }
//    Serial.println("90"); motor_servo_beacon.write(90);
//    delay(2000); Serial.println("90 OK");
//    motor_servo_beacon.detach();

#ifdef IR_PIN_PWM
//    pwm_front.begin(PIN_BEACON_FRONT, HIGH); // PWM on pin x reading PWM HIGH duration
//    pwm_back.begin(PIN_BEACON_FRONT, HIGH); // PWM on pin x reading PWM HIGH duration
#endif
    digitalWrite(PIN_BEACONS_ENABLE, HIGH);
}

String inString = "";

void beacon_calculate(uint32_t pwm_value_off, uint32_t pwm_value_on) {
    float pwm = 0;
    float period = 0;
    float freq = 0;
    period = pwm_value_off + pwm_value_on;
    freq = 1 / (period/1000000);
    pwm = (pwm_value_off / period);
    Serial.print("+ ");
    Serial.print(pwm_value_on);
    Serial.print("\t\t");
    Serial.print("- ");
    Serial.print(pwm_value_off);
    Serial.print("\t\t");
    Serial.print("P ");
    Serial.print((unsigned int) period);
    Serial.print("\t\t");
    Serial.print("F ");
    Serial.print(freq);
    Serial.print("\t\t");
    Serial.print("V ");
    Serial.print(pwm);
    Serial.println("");
}

// the loop function runs over and over again forever
void loop() {
    while (Serial.available() > 0) {
        int inChar = Serial.read();
        if (isDigit(inChar)) {
            // convert the incoming byte to a char and add it to the string:
            inString += (char)inChar;
        }
        // if you get a newline, print the string, then the string's value:
        if (inChar == '\n') {
            int value = inString.toInt();
            bool was_attached = motor_servo_beacon.attached();
            if (!was_attached) {
                motor_servo_beacon.attach(PIN_MOTOR_SERVO);
            }
            Serial.println(value); motor_servo_beacon.write(value);
            delay(2000); Serial.print(value); Serial.println(" OK");

            if (!was_attached) {
                motor_servo_beacon.detach();
            }
            // clear the string for new input:
            inString = "";
        }
    }

    digitalWrite(PIN_BEACONS_ENABLE, HIGH);
    delay(10);


#ifdef IR_PIN_INT
    pwm = 0;
    period = 0;
    p_period = 0;
    freq = 0;
    pwm_value_on = 0;
    pwm_value_off = 0;
    prev_time_on = 0;
    prev_time_off = 0;
    beacons_enabled = true;
#endif

#ifdef IR_PIN_IRREMOTE
    if (irrecv.decode(&results)) {
        Serial.println(results.value, HEX);
        irrecv.resume(); // Receive the next value
    }
    delay(100);
#endif

    Serial.print("*");
    digitalWrite(PIN_LED_RED, HIGH);   // turn the LED on (HIGH is the voltage level)
    delay(250);                       // wait for a second
    Serial.print(".");
    digitalWrite(PIN_LED_RED, LOW);    // turn the LED off by making the voltage LOW
    delay(250);                       // wait for a second
    Serial.println();

#ifdef IR_PIN_INT
//    period = pwm_value_off + pwm_value_on;
//    freq = 1 / (period/1000000);
//    pwm = (pwm_value_off / period);
//    if (p_period != period) {
//        Serial.print("+ ");
//        Serial.println(pwm_value_on);
//        Serial.print("- ");
//        Serial.println(pwm_value_off);
//        Serial.print("P ");
//        Serial.println(period);
//        Serial.print("F ");
//        Serial.println(freq);
//        Serial.print("V ");
//        Serial.println(pwm);
//        Serial.println("");
//        p_period = period;
//    }
    beacon_calculate(pwm_value_off, pwm_value_on);
    beacons_enabled = false;
#endif


#ifdef IR_PIN_PWM
    IR_PWM pwm_front;
    pwm_front.begin(PIN_BEACON_FRONT); // PWM on pin x reading PWM HIGH duration
    delay(1000);
    for (int i = 0; i < 4; i++) {
//        Serial.print("F "); Serial.println(pwm_front.getValue());
        Serial.print("F ");
        beacon_calculate(pwm_front.getValueLow(), pwm_front.getValueHigh());
        delay(100);
    }
    IR_PWM pwm_back;
    pwm_back.begin(PIN_BEACON_BACK); // PWM on pin x reading PWM HIGH duration
    delay(1000);
    for (int i = 0; i < 4; i++) {
//        Serial.print("B "); Serial.println(pwm_back.getValue());
        Serial.print("B ");
        beacon_calculate(pwm_back.getValueLow(), pwm_back.getValueHigh());
        delay(100);
    }

#endif
    delay(10);
    digitalWrite(PIN_BEACONS_ENABLE, LOW);
    delay(100);
}

#ifdef IR_PIN_INT

void rising() {
    attachInterrupt(digitalPinToInterrupt(IR_PIN), falling, FALLING);
    if (!beacons_enabled) return;
    prev_time_on = micros();

    pwm_value_off = micros() - prev_time_off;

//    Serial.print("-");
//    Serial.println(pwm_value_off);
}
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

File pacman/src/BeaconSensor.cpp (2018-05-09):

//
// Created by Pedro Costa on 06/05/18.
//

#include "BeaconSensor.h"

// Global variables for ISR routines
unsigned int value_HIGH[6];
unsigned int value_LOW[6];
unsigned long timers_HIGH[6];
unsigned long timers_LOW[6];
bool ISR_enabled = false;

void ISR_2_rising();
void ISR_2_falling();
void ISR_3_rising();
void ISR_3_falling();
void ISR_18_rising();
void ISR_18_falling();
void ISR_19_rising();
void ISR_19_falling();
void ISR_20_rising();
void ISR_20_falling();
void ISR_21_rising();
void ISR_21_falling();

// ISR for pin 2
void ISR_2_rising() {
    attachInterrupt(digitalPinToInterrupt(2), ISR_2_falling, FALLING);
    if (!ISR_enabled) return;
    unsigned long now = micros();
    timers_HIGH[0] = now;
    value_LOW[0] = (unsigned int) (now - timers_LOW[0]);
}
void ISR_2_falling() {
    attachInterrupt(digitalPinToInterrupt(2), ISR_2_rising, RISING);
    if (!ISR_enabled) return;
    unsigned long now = micros();
    timers_LOW[0] = now;
    value_HIGH[0] = (unsigned int) (now - timers_HIGH[0]);
}

// ISR for pin 3
void ISR_3_rising() {
    attachInterrupt(digitalPinToInterrupt(3), ISR_3_falling, FALLING);
    if (!ISR_enabled) return;
    unsigned long now = micros();
    timers_HIGH[1] = now;
    value_LOW[1] = (unsigned int) (now - timers_LOW[1]);
}
void ISR_3_falling() {
    attachInterrupt(digitalPinToInterrupt(3), ISR_3_rising, RISING);
    if (!ISR_enabled) return;
    unsigned long now = micros();
    timers_LOW[1] = now;
    value_HIGH[1] = (unsigned int) (now - timers_HIGH[1]);
}

// ISR for pin 18
void ISR_18_rising() {
    attachInterrupt(digitalPinToInterrupt(18), ISR_18_falling, FALLING);
    if (!ISR_enabled) return;
    unsigned long now = micros();
    timers_HIGH[2] = now;
    value_LOW[2] = (unsigned int) (now - timers_LOW[2]);
}
void ISR_18_falling() {
    attachInterrupt(digitalPinToInterrupt(18), ISR_18_rising, RISING);
    if (!ISR_enabled) return;
    unsigned long now = micros();
    timers_LOW[2] = now;
    value_HIGH[2] = (unsigned int) (now - timers_HIGH[2]);
}

// ISR for pin 19
void ISR_19_rising() {
    attachInterrupt(digitalPinToInterrupt(19), ISR_19_falling, FALLING);
    if (!ISR_enabled) return;
    unsigned long now = micros();
    timers_HIGH[3] = now;
    value_LOW[3] = (unsigned int) (now - timers_LOW[3]);
}
void ISR_19_falling() {
    attachInterrupt(digitalPinToInterrupt(19), ISR_19_rising, RISING);
    if (!ISR_enabled) return;
    unsigned long now = micros();
    timers_LOW[3] = now;
    value_HIGH[3] = (unsigned int) (now - timers_HIGH[3]);
}

// ISR for pin 20
void ISR_20_rising() {
    attachInterrupt(digitalPinToInterrupt(20), ISR_20_falling, FALLING);
    if (!ISR_enabled) return;
    unsigned long now = micros();
    timers_HIGH[4] = now;
    value_LOW[4] = (unsigned int) (now - timers_LOW[4]);
}
void ISR_20_falling() {
    attachInterrupt(digitalPinToInterrupt(20), ISR_20_rising, RISING);
    if (!ISR_enabled) return;
    unsigned long now = micros();
    timers_LOW[4] = now;
    value_HIGH[4] = (unsigned int) (now - timers_HIGH[4]);
}
// ISR for pin 21
void ISR_21_rising() {
    attachInterrupt(digitalPinToInterrupt(21), ISR_21_falling, FALLING);
    if (!ISR_enabled) return;
    unsigned long now = micros();
    timers_HIGH[5] = now;
    value_LOW[5] = (unsigned int) (now - timers_LOW[5]);
}
void ISR_21_falling() {
    attachInterrupt(digitalPinToInterrupt(21), ISR_21_rising, RISING);
    if (!ISR_enabled) return;
    unsigned long now = micros();
    timers_LOW[5] = now;
    value_HIGH[5] = (unsigned int) (now - timers_HIGH[5]);
}

// Begin function to setup interrupt and attach ISR
void IR_PWM::begin(byte pin,
                   float min_freq_threshold,
                   float max_freq_threshold,
                   float min_pwm_threshold,
                   float max_pwm_threshold) {
    IR_PWM::min_freq_threshold = min_freq_threshold;
    IR_PWM::max_freq_threshold = max_freq_threshold;
    IR_PWM::min_pwm_threshold = min_pwm_threshold;
    IR_PWM::max_pwm_threshold = max_pwm_threshold;
    begin(pin);
}

void IR_PWM::begin() {
    begin(pin);
}

void IR_PWM::begin(byte pin) {
    IR_PWM::pin = pin;
    switch (pin) {
        case 2:
            value_HIGH[0] = 0;
            value_LOW[0] = 0;
            timers_HIGH[0] = 0;
            timers_LOW[0] = 0;
            attachInterrupt(digitalPinToInterrupt(pin), ISR_2_rising, RISING);
            break;
        case 3:
            value_HIGH[1] = 0;
            value_LOW[1] = 0;
            timers_HIGH[1] = 0;
            timers_LOW[1] = 0;
            attachInterrupt(digitalPinToInterrupt(pin), ISR_3_rising, RISING);
            break;
        case 18:
            value_HIGH[2] = 0;
            value_LOW[2] = 0;
            timers_HIGH[2] = 0;
            timers_LOW[2] = 0;
            attachInterrupt(digitalPinToInterrupt(pin), ISR_18_rising, RISING);
            break;
        case 19:
            value_HIGH[3] = 0;
            value_LOW[3] = 0;
            timers_HIGH[3] = 0;
            timers_LOW[3] = 0;
            attachInterrupt(digitalPinToInterrupt(pin), ISR_19_rising, RISING);
            break;
        case 20:
            value_HIGH[4] = 0;
            value_LOW[4] = 0;
            timers_HIGH[4] = 0;
            timers_LOW[4] = 0;
            attachInterrupt(digitalPinToInterrupt(pin), ISR_20_rising, RISING);
            break;
        case 21:
            value_HIGH[5] = 0;
            value_LOW[5] = 0;
            timers_HIGH[5] = 0;
            timers_LOW[5] = 0;
            attachInterrupt(digitalPinToInterrupt(pin), ISR_21_rising, RISING);
            break;
        default:
            break;
    }
}


// Function to return channel value
unsigned int IR_PWM::getValueHigh() {
    switch (pin) {
        case 2:
            return value_HIGH[0];
        case 3:
            return value_HIGH[1];
        case 18:
            return value_HIGH[2];
        case 19:
            return value_HIGH[3];
        case 20:
            return value_HIGH[4];
        case 21:
            return value_HIGH[5];
        default:
            break;
    }
}

unsigned int IR_PWM::getValueLow() {
    switch (pin) {
        case 2:
            return value_LOW[0];
        case 3:
            return value_LOW[1];
        case 18:
            return value_LOW[2];
        case 19:
            return value_LOW[3];
        case 20:
            return value_LOW[4];
        case 21:
            return value_LOW[5];
        default:
            break;
    }
}

void IR_PWM::calculateValues() {
    low = getValueLow();
    high = getValueHigh();
    period = low + getValueHigh();
    freq = 1 / (period/1000000);
    pwm = (low / period);
}
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
